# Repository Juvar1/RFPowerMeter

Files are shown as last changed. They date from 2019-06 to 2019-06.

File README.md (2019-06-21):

# RFPowerMeter
RF power meter and supply voltage meter for battery powered transmitter.

## First prototype

Version 1.0

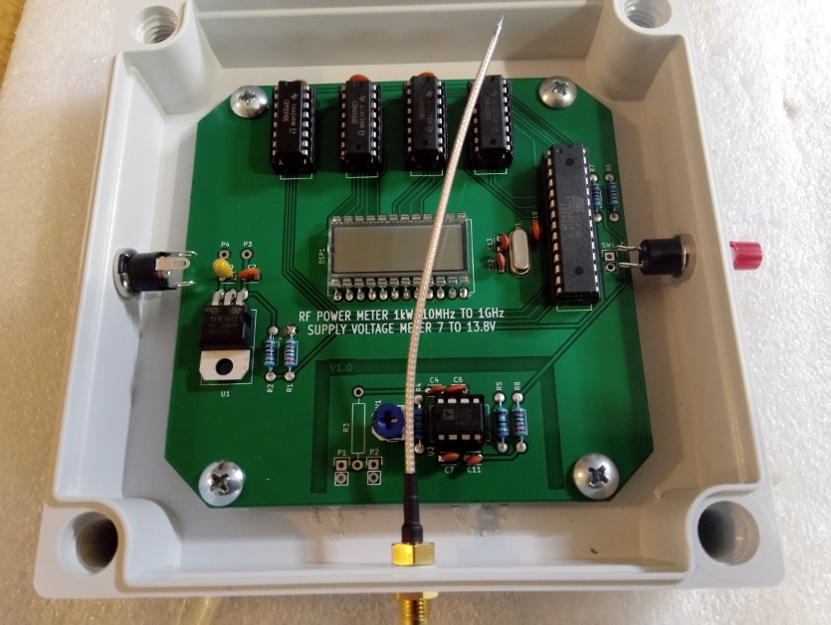
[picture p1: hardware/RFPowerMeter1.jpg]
Proto


## 3D image

Version 1.1

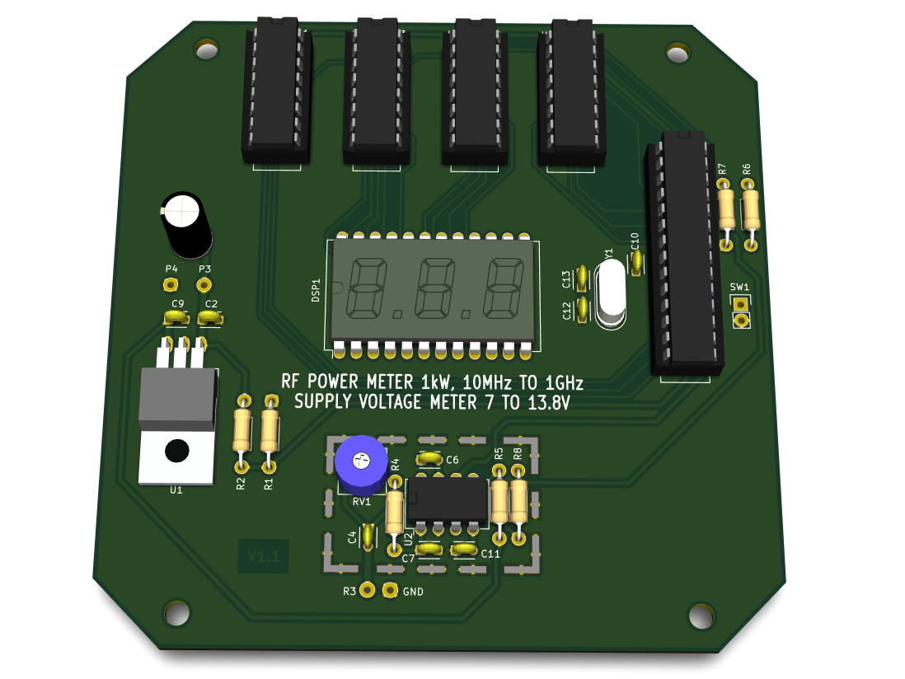
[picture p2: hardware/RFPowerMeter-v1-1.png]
PCB


## Introduction

This meter measures the transmitting power of the radio transmitter and the voltage of the battery used as a power source. Power is displayed in watts and dBm. The device has a three-digit LCD display. The functions are controlled by a push button. The unit will automatically turn off after one minute if the button is not pressed. By pressing about 1-2 seconds device wakes from sleep mode and show measured power in watts. By pressing again device switches to dBm mode and show power in dBm. Pressing third time device show measured supply voltage. If voltage is over measuring range display shows '999'.

Comes as a bag of parts kit and is easily assembled if customer can follow the silkscreen indicators and have beginning experience with a soldering iron. Customer will need to read the resistor bands or use a multimeter to determine the resistor sizes.

Works with single 7…14 volts DC power supply connected with DC barrel plug. Internally 5.0V voltage is used through regulator 7805. ADC reference voltage is taken from supply voltage with voltage divider. Its voltage is 2.5V. One analog input is connected with supply voltage also with voltage divider. its voltage is adjusted to a max. of 2.5V at 14V so that accurate voltage measurement is made possible.

The heart of the device is AtMega328P-PU at 16MHz clock frequency. This makes it to be Arduino™ compatible system.

For measuring power, an AD8307 chip is used. It allows the RF power to be converted to a voltage between 0 and 2.5V. The permissible power is between 0 and 1kW. The permissible frequency range is between 10MHz and 1GHz. It is possible to calibrate the measuring range by ± 3dB with on-board trimmer resistor. The output is connected to the analog input of the microcontroller.

Measurement is made with following two equations:

dBm = 40(U-1)
<br>W = 10(dBm/10)/1000

The display is a three-digit LCD display. LCD display requires AC voltage. It can be simple square wave signal from DC 5V. Frequency is not critical. It can be between 30-200Hz. Phase difference lights the segment. This device uses regular CMOS series IC’s to control LCD segments. 4056 is used to control digits. Every digit needs own IC. One 4054 is used to control two decimal points and to invert common backplane signal. Frequency is made with Arduino™ PWM output. It is about 30Hz.

Current consumption is very low because of CMOS integrated circuits used and AtMega328P power saving mode which is programmatically activated. LCD display consumes very little current compared to regular LED display. Also power measurement circuit ’chip enable’ signal is controlled with AVR.

## Casing

Physical size of device is with casing 13x13cm. PCB is 10x10cm. Dimensions excludes connectors and push button. Case is bought from Digi-Key like all other parts. It’s part number is [PIP-11766-C](https://www.digikey.fi/product-detail/en/bud-industries/PIP-11766-C/377-2127-ND/4896970). DC jack outer diameter is 5.5mm and inner 2.5mm.

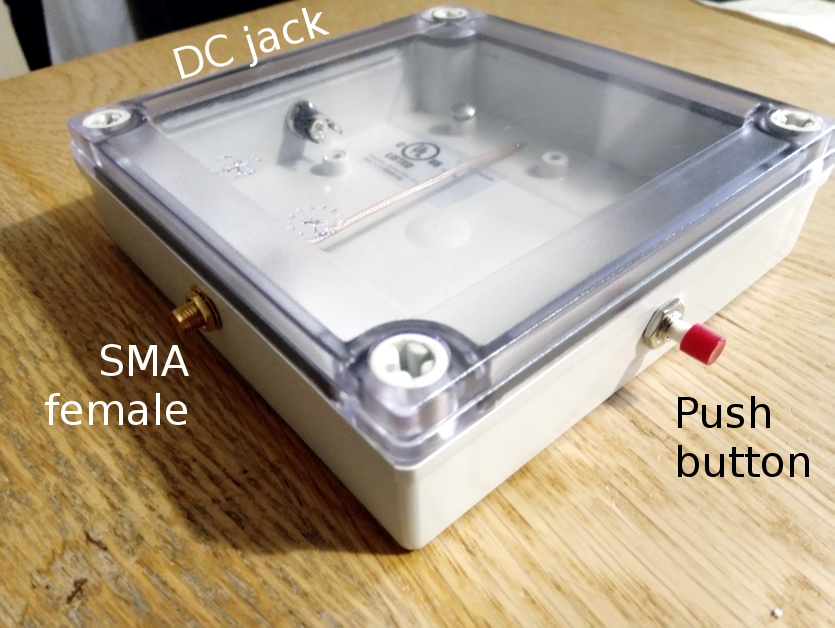
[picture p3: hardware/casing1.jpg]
casing


## Usage examples

- Amateur radio station power meter
- Power measurement

## Circuit diagram

Revision 3: Improved supply line and button noise immunity.
<br>Revision 2: Improved measuring circuit noise immunity.

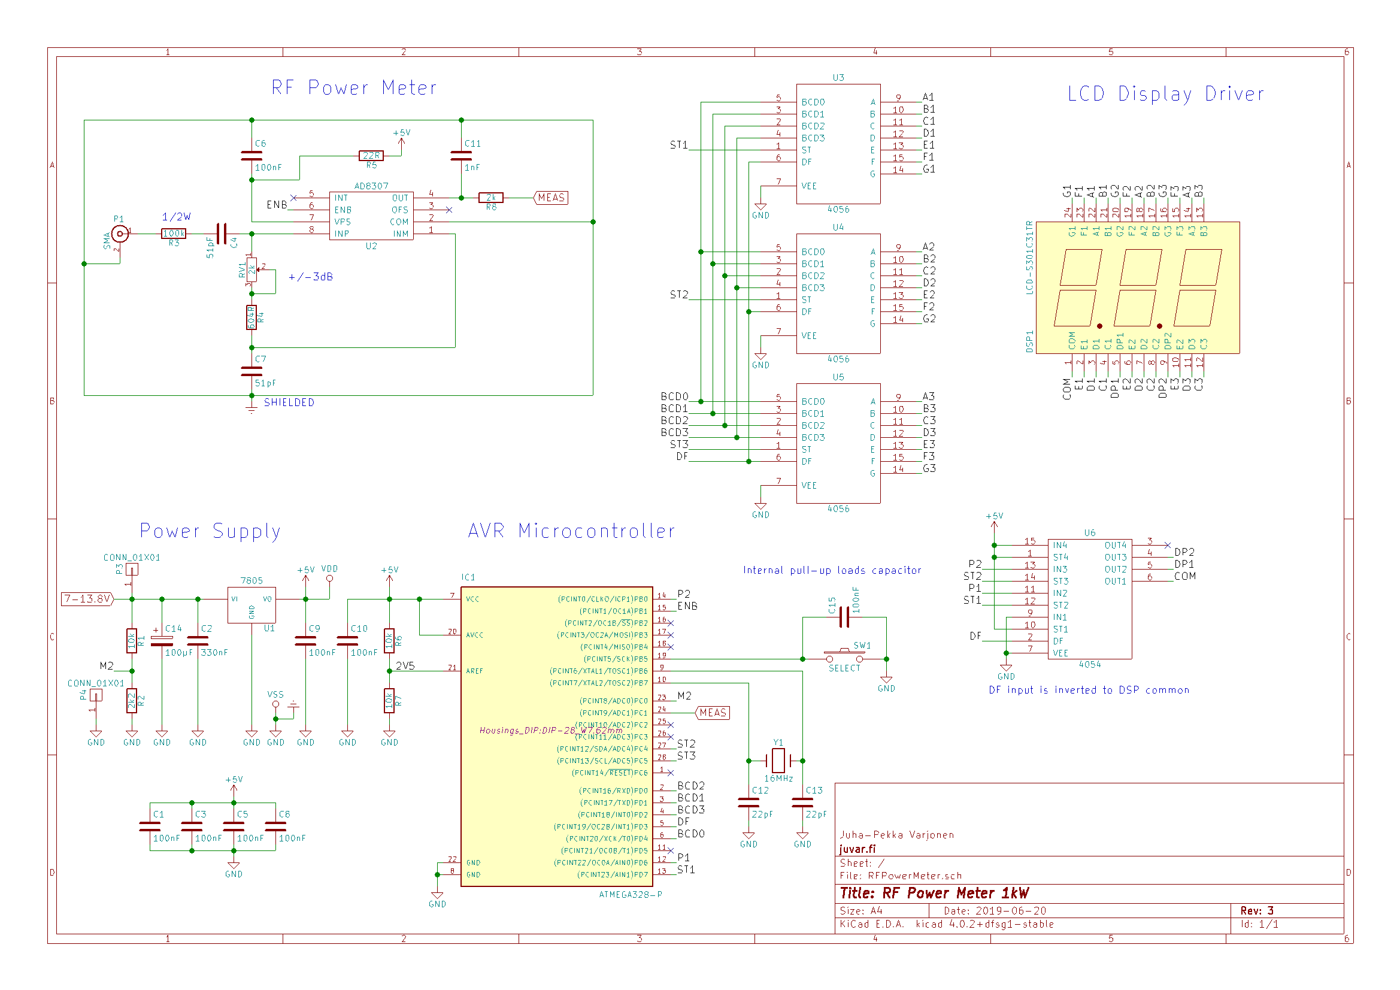
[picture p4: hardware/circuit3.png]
circuit diagram


## Development stage

One prototype has been ordered so far with double sided printed circuit board and with through hole components. It is designed with KiCad. Tested and working.

## Advantages

Ease of use. The device has only one button with three functions. ’Plug-and-play’. Safe operating voltage. Safe to use. Hackable design.

## Other similar devices

Surecom SW-102 Digital Antenna Power & SWR Meter VHF/UHF 125-525MHz. Used for reference and calibration.

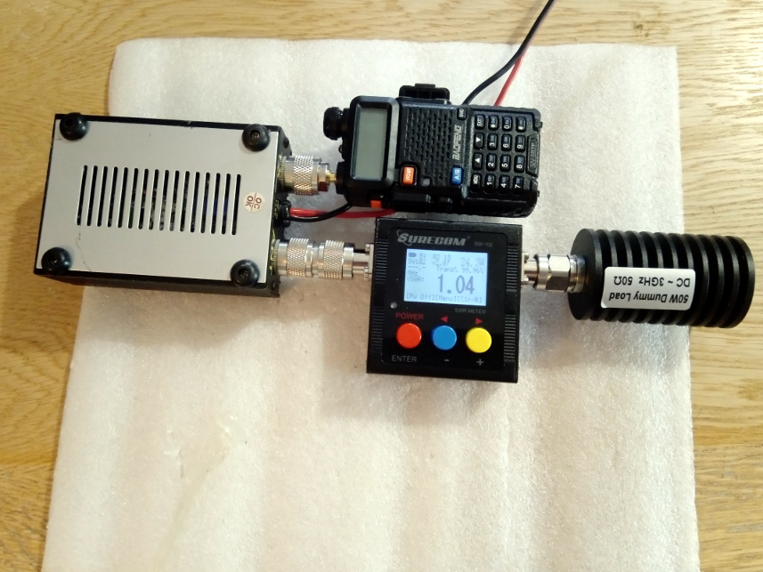
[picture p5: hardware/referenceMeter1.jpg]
Reference meter


## Soldering

The project requires no special soldering skills. All components are their through hole versions.

## Programming

All parts are open source. The program is solely written in C++. The program is very simple and with its 200 lines of code it uses only 4.6kB of program memory. AtMega328P-PU chip is used.

The bootloader must first be programmed using external programmer. I personally like to use Arduino™ as ISP and Arduino™ IDE. Be sure to choose the Arduino™ Uno from the Tools→Board menu. After installing the bootloader, the program can be uploaded using same setup.

Program does not use any external libraries. Only standard built-in power saving related libraries are used.

## Approvals

Arduino is a registered trademark. It is still ok to build a commercial product based on Arduino. Only the name may not be the same. https://www.arduino.cc/en/Main/FAQ#toc10

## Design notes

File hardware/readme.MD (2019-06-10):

Printed circuit board is designed with KiCad software.

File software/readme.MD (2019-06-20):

Software to work with Arduino bootloader. Programmed with Arduino IDE.

Tested and working version.

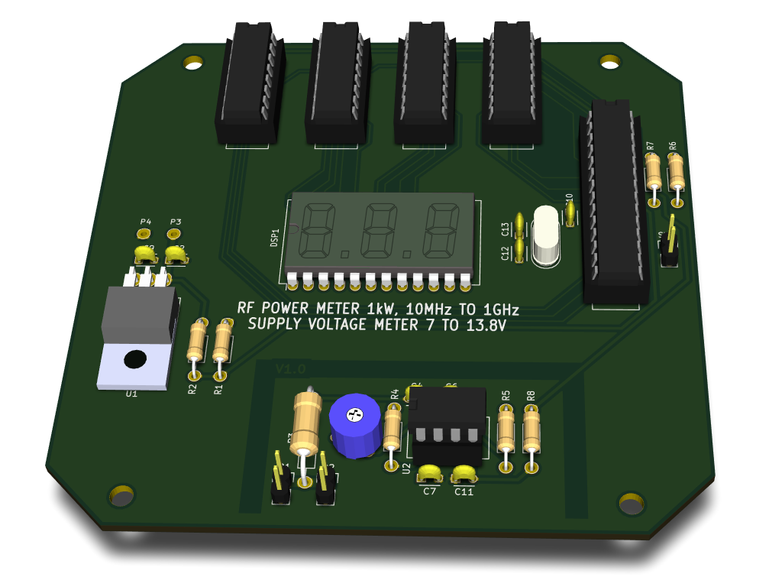
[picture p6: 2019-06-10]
hardware/RFPowerMeter.png

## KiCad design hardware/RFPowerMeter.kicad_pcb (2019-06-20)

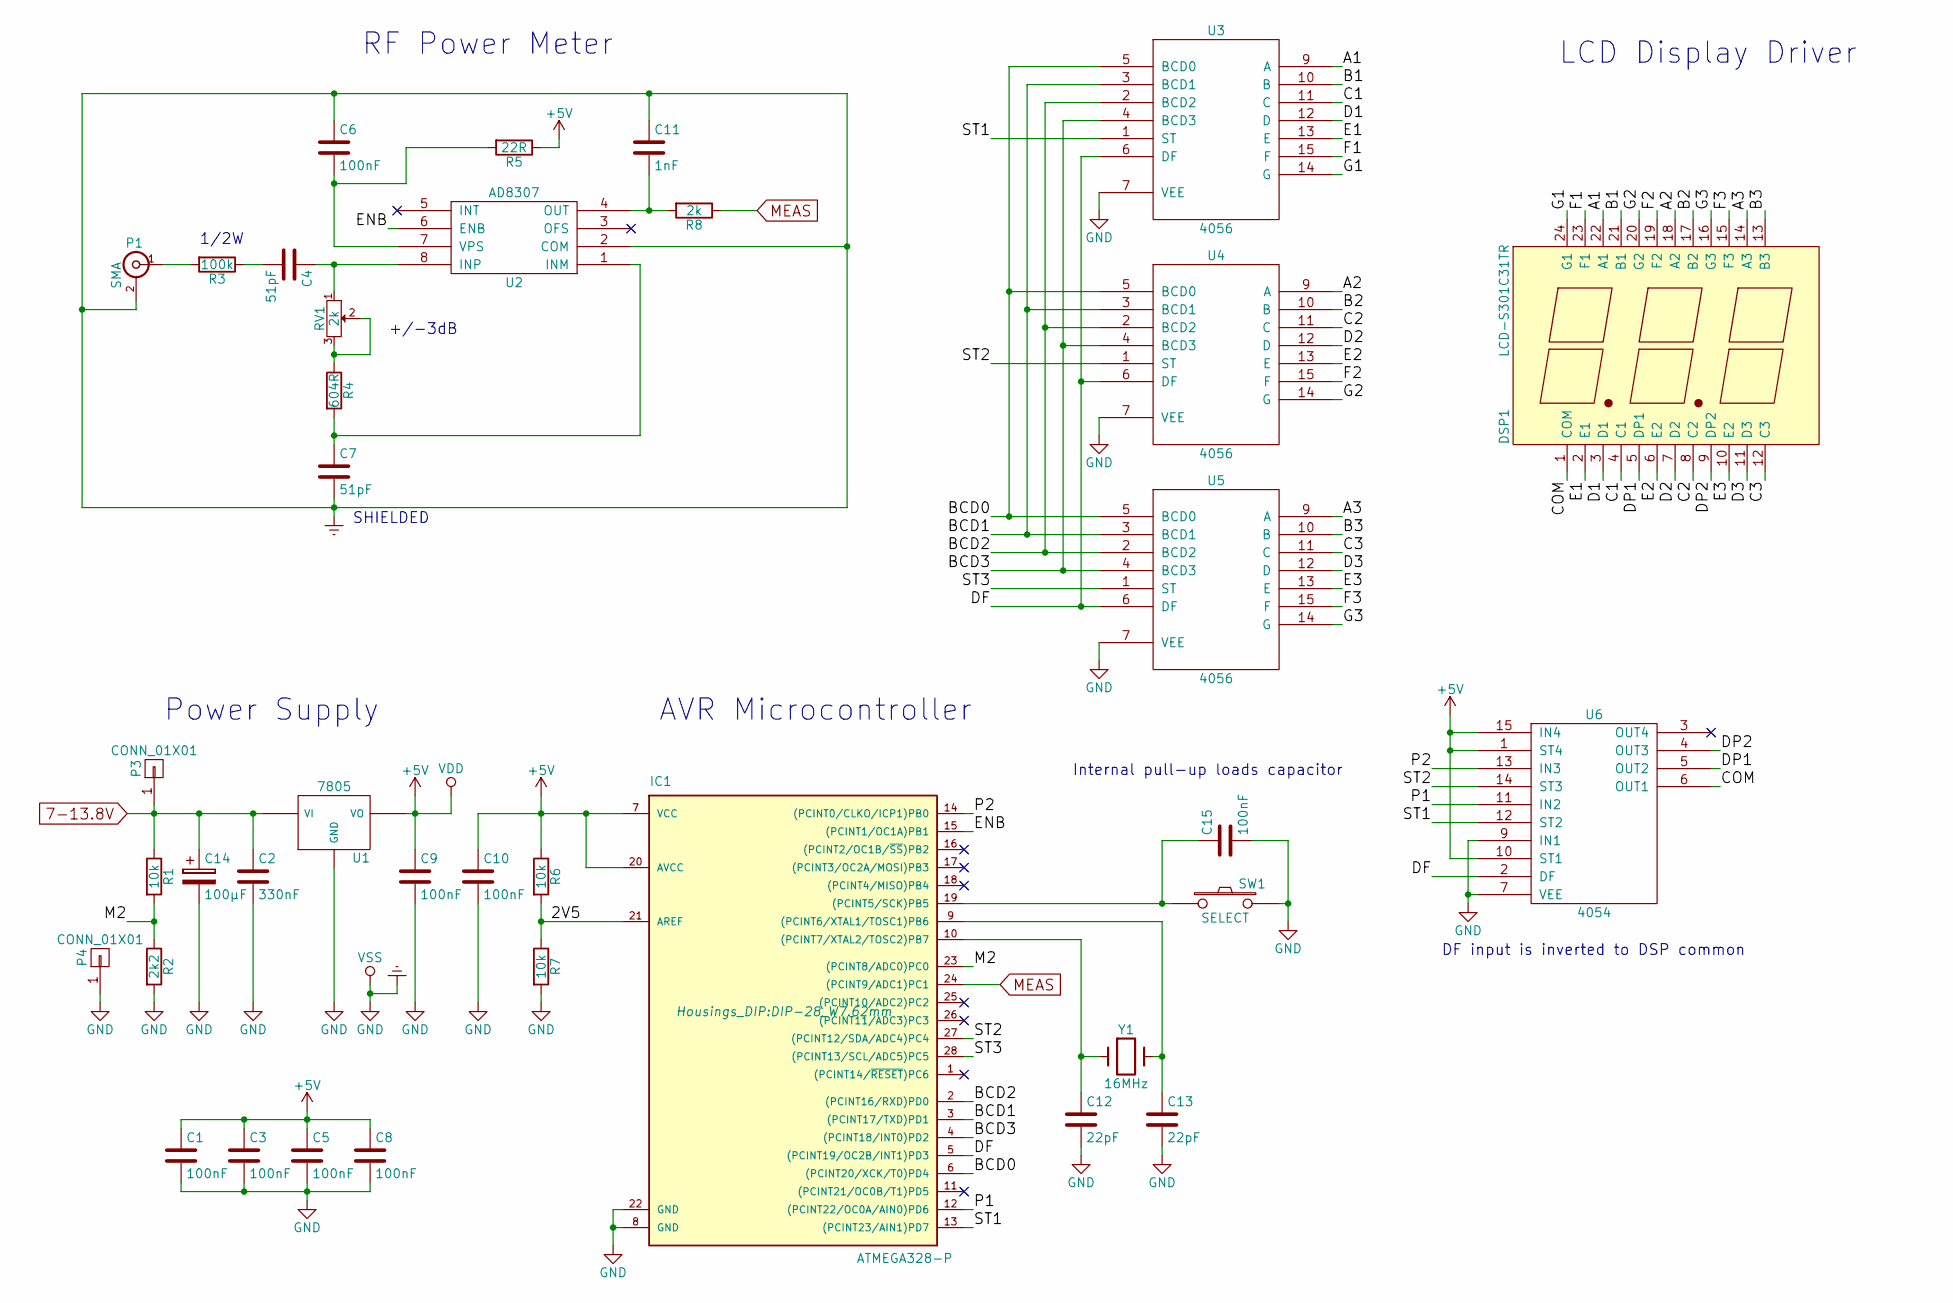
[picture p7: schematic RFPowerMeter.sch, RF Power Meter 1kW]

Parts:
C1, C3, C5, C6, C8, C9, C10, C15: 100nF; C_Disc_D3_P2.5
C2: 330nF; C_Disc_D3_P2.5
C4, C7: 51pF; C_Disc_D3_P2.5
C11: 1nF; C_Disc_D3_P2.5
C12, C13: 22pF; C_Disc_D3_P2.5
C14: 100µF; C_Radial_D6.3_L11.2_P2.5
DSP1: LCD-S301C31TR; LCD-24-PIN
IC1: ATMEGA328-P; DIP-28_W7.62mm
P1: SMA
P3, P4: CONN_01X01; SolderWirePad_single_1-2mmDrill
R1, R6, R7: 10k; Resistor_Horizontal_RM10mm
R2: 2k2; Resistor_Horizontal_RM10mm
R3: 100k; SolderWirePad_single_1-2mmDrill
R4: 604R; Resistor_Horizontal_RM10mm
R5: 22R; Resistor_Horizontal_RM10mm
R8: 2k; Resistor_Horizontal_RM10mm
RV1: 2k; Potentiometer_Bourns_3339P_Angular_ScrewUp
SW1: SELECT; Pin_Header_Straight_1x02
U1: 7805; TO-220_Neutral123_Horizontal
U2: AD8307; DIP-8_W7.62mm
U3, U4, U5: 4056; DIP-16_W7.62mm
U6: 4054; DIP-16_W7.62mm
Y1: 16MHz; Crystal_HC49-U_Vertical

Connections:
7-13.8V: C2.1, C14.1, P3.1, R1.1, U1.1 (VI); also elsewhere on the board
+5V: C1.1, C3.1, C5.1, C8.1, C9.1, C10.1, IC1.7 (VCC), IC1.20 (AVCC), R5.1, R6.1, U1.3 (VO), U3.16 (VDD), U4.16 (VDD), U5.16 (VDD), U6.1 (ST4), U6.10 (ST1), U6.15 (IN4), U6.16 (VDD)
/2V5: IC1.21 (AREF), R6.2, R7.1
/A1: DSP1.22 (A1), U3.9 (A)
/A2: DSP1.18 (A2), U4.9 (A)
/A3: DSP1.14 (A3), U5.9 (A)
/B1: DSP1.21 (B1), U3.10 (B)
/B2: DSP1.17 (B2), U4.10 (B)
/B3: DSP1.13 (B3), U5.10 (B)
/BCD0: IC1.6 ((PCINT20/XCK/T0)PD4), U3.5 (BCD0), U4.5 (BCD0), U5.5 (BCD0)
/BCD1: IC1.3 ((PCINT17/TXD)PD1), U3.3 (BCD1), U4.3 (BCD1), U5.3 (BCD1)
/BCD2: IC1.2 ((PCINT16/RXD)PD0), U3.2 (BCD2), U4.2 (BCD2), U5.2 (BCD2)
/BCD3: IC1.4 ((PCINT18/INT0)PD2), U3.4 (BCD3), U4.4 (BCD3), U5.4 (BCD3)
/C1: DSP1.4 (C1), U3.11 (C)
/C2: DSP1.8 (C2), U4.11 (C)
/C3: DSP1.12 (C3), U5.11 (C)
/COM: DSP1.1 (COM), U6.6 (OUT1)
/D1: DSP1.3 (D1), U3.12 (D)
/D2: DSP1.7 (D2), U4.12 (D)
/D3: DSP1.11 (D3), U5.12 (D)
/DF: IC1.5 ((PCINT19/OC2B/INT1)PD3), U3.6 (DF), U4.6 (DF), U5.6 (DF), U6.2 (DF)
/DP1: DSP1.5 (DP1), U6.5 (OUT2)
/DP2: DSP1.9 (DP2), U6.4 (OUT3)
/E1: DSP1.2 (E1), U3.13 (E)
/E2: DSP1.6 (E2), U4.13 (E)
/E3: DSP1.10 (E2), U5.13 (E)
/ENB: IC1.15 ((PCINT1/OC1A)PB1), U2.6 (ENB)
/F1: DSP1.23 (F1), U3.15 (F)
/F2: DSP1.19 (F2), U4.15 (F)
/F3: DSP1.15 (F3), U5.15 (F)
/G1: DSP1.24 (G1), U3.14 (G)
/G2: DSP1.20 (G2), U4.14 (G)
/G3: DSP1.16 (G3), U5.14 (G)
/M2: IC1.23 ((PCINT8/ADC0)PC0), R1.2, R2.1
/P1: IC1.12 ((PCINT22/OC0A/AIN0)PD6), U6.11 (IN2)
/P2: IC1.14 ((PCINT0/CLKO/ICP1)PB0), U6.13 (IN3)
/ST1: IC1.13 ((PCINT23/AIN1)PD7), U3.1 (ST), U6.12 (ST2)
/ST2: IC1.27 ((PCINT12/SDA/ADC4)PC4), U4.1 (ST), U6.14 (ST3)
/ST3: IC1.28 ((PCINT13/SCL/ADC5)PC5), U5.1 (ST)
Earth: C1.2, C2.2, C3.2, C5.2, C6.1, C7.2, C8.2, C9.2, C10.2, C11.1, C12.2, C13.2, C14.2, C15.2, IC1.8 (GND), IC1.22 (GND), P1.2 (Ext), P4.1, R2.2, R7.2, SW1.2, U1.2 (GND), U1.4 (GND), U2.2 (COM), U3.7 (VEE), U3.8 (VSS), U4.7 (VEE), U4.8 (VSS), U5.7 (VEE), U5.8 (VSS), U6.7 (VEE), U6.8 (VSS), U6.9 (IN1); also elsewhere on the board
MEAS: IC1.24 ((PCINT9/ADC1)PC1), R8.1
unnamed: C4.1, RV1.1, U2.8 (INP)
unnamed: C4.2, R3.1
unnamed: C6.2, R5.2, U2.7 (VPS)
unnamed: C7.1, R4.2, U2.1 (INM)
unnamed: C11.2, R8.2, U2.4 (OUT)
unnamed: C12.1, IC1.10 ((PCINT7/XTAL2/TOSC2)PB7), Y1.1
unnamed: C13.1, IC1.9 ((PCINT6/XTAL1/TOSC1)PB6), Y1.2
unnamed: C15.1, IC1.19 ((PCINT5/SCK)PB5), SW1.1
unnamed: P1.1 (In), R3.2
unnamed: R4.1, RV1.2, RV1.3

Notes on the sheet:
1/2W
SHIELDED
RF Power Meter
LCD Display Driver
AVR Microcontroller
Power Supply
DF input is inverted to DSP common
+/-3dB
Internal pull-up loads capacitor

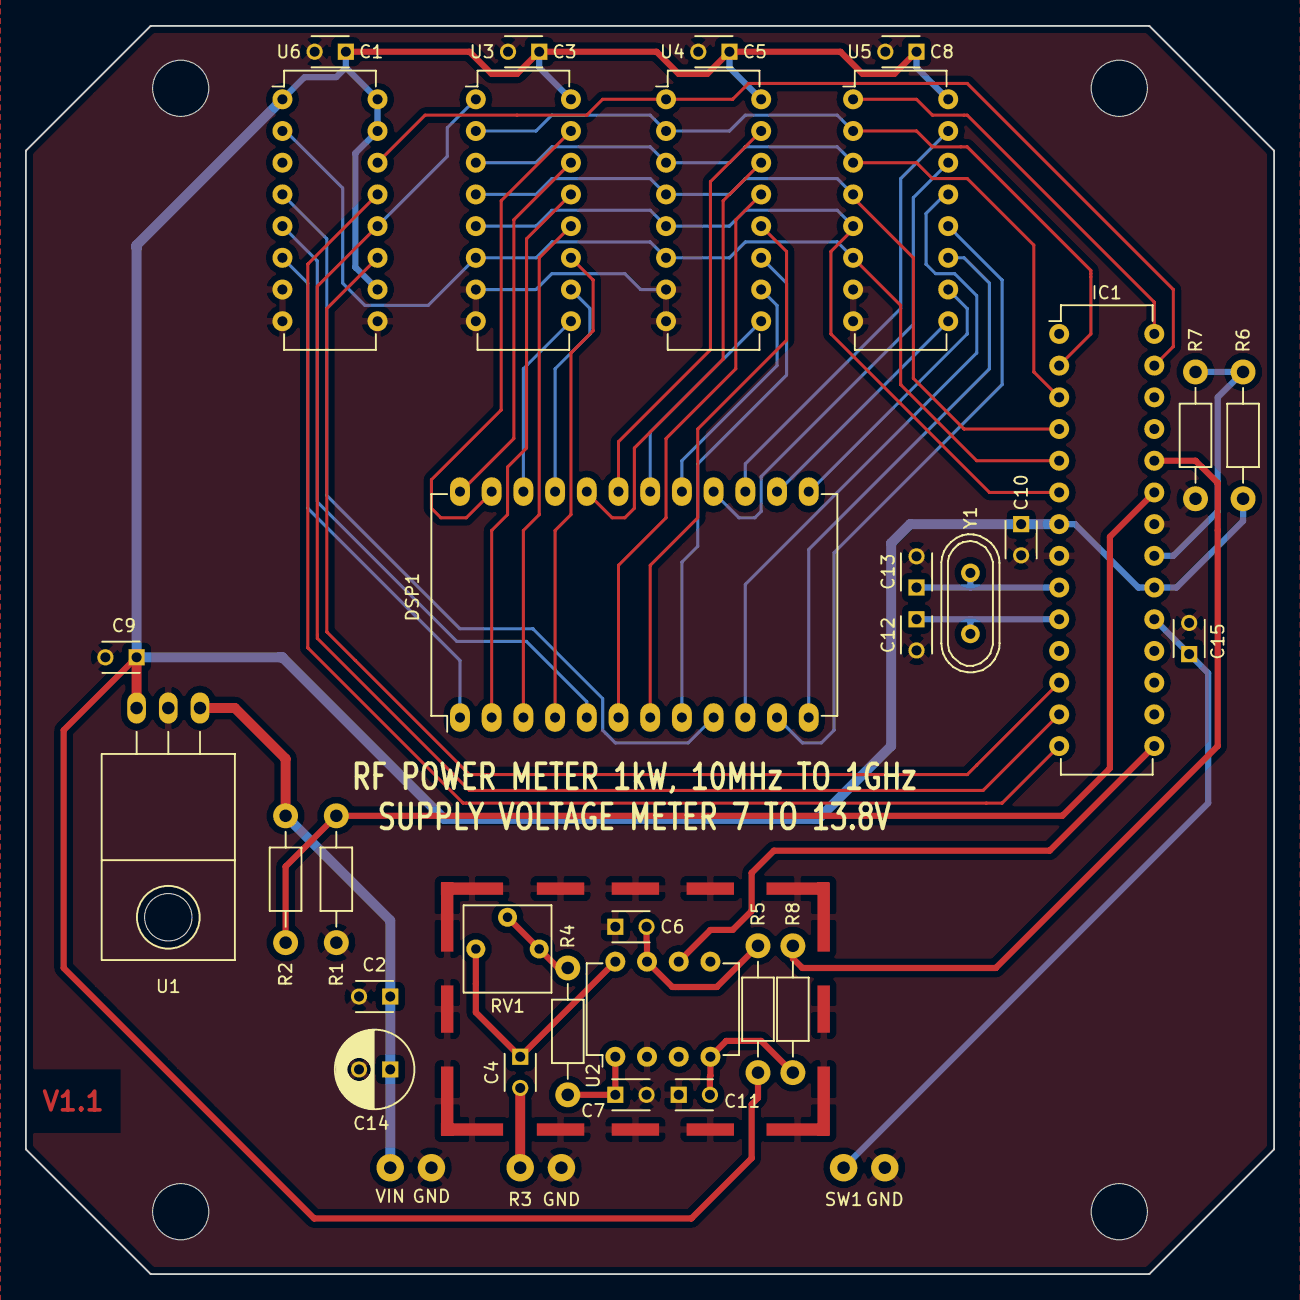
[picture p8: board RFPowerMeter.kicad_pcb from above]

Board: 2 copper layers, 100.0 x 100.0 mm, 38 parts (0 on the bottom side), 50 nets.

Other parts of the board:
GND: SolderWirePad_single_1-2mmDrill
GND#2: CONN_01X01; SolderWirePad_single_1-2mmDrill
GND#3: SolderWirePad_single_1-2mmDrill
VIN: CONN_01X01; SolderWirePad_single_1-2mmDrill

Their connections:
7-13.8V: VIN.1; also elsewhere on the board
Earth: GND.1, GND#2.1, GND#3.1; also elsewhere on the board

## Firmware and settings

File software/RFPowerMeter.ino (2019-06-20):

/* RFPowerMeter.ino
 * 
 * Displays 12V lead acid battery voltage level on display
 * and RF transmitting power on same display in watts or dBm
 * 
 * Author: jpvarjonen@gmail.com
 * Copyright (C) 2019 Juha-Pekka Varjonen
 * 
 * Goes to sleep and wakes every 2s to check button state
 */

#include <avr/sleep.h>
#include <avr/wdt.h>
#include <avr/power.h>

int measureState = 0;
int buttonState;             // the current reading from the input pin
int lastButtonState = HIGH;   // the previous reading from the input pin

unsigned long lastDebounceTime = 0;  // the last time the output pin was toggled
unsigned long debounceDelay = 100;   // the debounce time; increase if the output flickers
unsigned long shutdownDelay = 0;

void setup() {
  // power up settings
  wdt_enable(WDTO_2S);

  // display frequency always on
  TCCR2A = B00000000;
  TCCR2B = B00000110; //61Hz
  analogWrite(3,128); // 50% duty cycle

  // define outputs, default output state is low
  pinMode(0,OUTPUT);  // BCD2
  pinMode(1,OUTPUT);  // BCD1
  pinMode(2,OUTPUT);  // BCD3
  pinMode(4,OUTPUT);  // BCD0
  pinMode(6,OUTPUT);  // P1
  pinMode(7,OUTPUT);  // ST1
  pinMode(8,OUTPUT);  // P2
  pinMode(9,OUTPUT);  // ENB
  pinMode(A4,OUTPUT); // ST2
  pinMode(A5,OUTPUT); // ST3

  pinMode(13,INPUT_PULLUP); //button
  if (!digitalRead(13)) { // if pressed then wake up
    // set analog reference voltage to external
    analogReference(EXTERNAL); // 2.5V set by hardware
    // activate measurement
    digitalWrite(9, HIGH);
  } else {
    // if not pressed then go back to sleep
    goToSleep();
  }
}

void loop() {

  wdt_reset(); // prevent sleep

  changeReading(); // read button state, takes >500ms

  wdt_reset(); // prevent sleep

  long result = 0; // decimal point removed with '* 100'
  if (measureState == 0) { // RF power in watts
    float val = analogRead(A1);
    float PdBm = 40*((2.5/1023*val)-1);
    float PW = pow(10,(PdBm/10))/1000;
    result = (long)(PW * 100);
  }
  else if (measureState == 1) { // RF power in dBm
    float val = analogRead(A1);
    float PdBm = 40*((2.5/1023*val)-1);
    result = (long)(PdBm * 100);
  }
  else if (measureState == 2) { // supply voltage measurement
    float val = analogRead(A0);
    float voltage = (12.205/1023*val);
    if(val == 1023) voltage = 999;
    result = (long)(voltage * 100);
  }
  
  short shift = 0;

  if (result < 0) {
    shift = 1;
    result = -result;
    writeToDisplay(1, 0xe, false); // minus sign
  }
  
  boolean dp1 = false;
  boolean dp2 = false;

  if (result < 999) {
    dp1 = true;
  }
  if (result > 999) {
    result = result / 10;
    dp2 = true;
  }
  if (result > 999) {
    result = result / 10;
    dp2 = false;
  }

  writeToDisplay(1 + shift, (int)(result / 100), dp1);
  writeToDisplay(2 + shift, (int)((result % 100) / 10), dp2);
  if (shift == 0) writeToDisplay(3, (int)(result % 10), false);

  //if 1 minute is up from last button press
  if (millis() - shutdownDelay >= 60000) {
    writeToDisplay(1,0xf,false);
    writeToDisplay(2,0xf,false);
    writeToDisplay(3,0xf,false);
    digitalWrite(9, LOW); // deactivate measurement
    goToSleep();
  }
  
}

void changeReading() {
  int reading = digitalRead(13);
  // If the switch changed, due to noise or pressing:
  if (reading != lastButtonState) {
    // reset the debouncing timer
    lastDebounceTime = millis();
  }
    if ((millis() - lastDebounceTime) > debounceDelay) {
    // whatever the reading is at, it's been there for longer than the debounce
    // delay, so take it as the actual current state:

    // if the button state has changed:
    if (reading != buttonState) {
      buttonState = reading;

      // only use state if the new button state is LOW
      if (buttonState == LOW) {
        measureState++;
        if(measureState > 2) { measureState = 0; }
        
        // display measurement state 'icon'
        if(measureState == 0) {
          writeToDisplay(1,0xc,false); //P
          writeToDisplay(2,0,false);   //0
          writeToDisplay(3,1,false);   //1
        } else if(measureState == 1) {
          writeToDisplay(1,0xc,false); //P
          writeToDisplay(2,0,false);   //0
          writeToDisplay(3,2,false);   //2
        } else if(measureState == 2) {
          writeToDisplay(1,0xb,false); //H
          writeToDisplay(2,1,false);   //1
          writeToDisplay(3,0xf,false); //(blank)
        }
        delay(500);
        shutdownDelay = millis(); // button resets the timeout
      }
    }
  }
  // save the reading. Next time through the loop, it'll be the lastButtonState:
  lastButtonState = reading;
}

void writeToDisplay(int disp, int number, boolean dp) {

  // error correction
  if(number > 0xf || number < 0) { number = 0xf; }
  if(disp > 3) { return; }

  //encode BCD code
  digitalWrite(2,(number & 0b1000) >> 3);
  digitalWrite(0,(number & 0b100) >> 2);
  digitalWrite(1,(number & 0b10) >> 1);
  digitalWrite(4,number & 0b1);
  digitalWrite(6, LOW); // decimal point initialization
  digitalWrite(8, LOW); // other decimal point

  // strobe
  if(disp == 1) {
    if(dp) { digitalWrite(6, HIGH); }
    digitalWrite(7, HIGH);
  }
  else if(disp == 2) {
    if(dp) { digitalWrite(8, HIGH); }
    digitalWrite(A4, HIGH);
  }
  else if(disp == 3) {digitalWrite(A5, HIGH);}
  delay(15);
  if(disp == 1) {digitalWrite(7, LOW);}
  else if(disp == 2) {digitalWrite(A4, LOW);}
  else if(disp == 3) {digitalWrite(A5, LOW);}
  delay(15);
}

void goToSleep() {
  // set sleep mode (not activated yet)
  set_sleep_mode(SLEEP_MODE_PWR_DOWN);
  // disable things
  power_spi_disable();
  power_usart0_disable();
  power_twi_disable();
  power_timer0_disable();
  power_timer1_disable();
  //power_timer2_disable();
  power_adc_disable();
  // go to sleep (watchdog will restart)
  sleep_mode();
}

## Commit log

2019-06-14 Improved noise immunity
    [RFPowerMeter.kicad_pcb, RFPowerMeter.sch]
2019-06-20 Improved noice immunity, fixed hole sizes
    [RFPowerMeter.kicad_pcb, RFPowerMeter.sch]
2019-06-20 fixed decimal point position
    [RFPowerMeter.ino]
